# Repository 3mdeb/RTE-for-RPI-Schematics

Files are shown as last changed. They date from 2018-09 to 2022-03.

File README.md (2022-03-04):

# Schematics of the RTE platform for Raspberry Pi

This repository contains source files for Remote Testing Environment schematics.

If you want to read more about this project, here are some useful links:

* Firmware/software:
  - meta-rte - custom firmware for RTE RPi [TBD]
  - [RteCtrl](https://github.com/3mdeb/RteCtrl) - binary for power management on
  board ([MIT license](https://github.com/3mdeb/RteCtrl/blob/master/LICENSE))
* Datasheet (under CC BY-SA 4.0 International License):
  - [RTE RPi v0.1.2 datasheet](https://cloud.3mdeb.com/index.php/s/cM5Mi4w2mjKNpBY)

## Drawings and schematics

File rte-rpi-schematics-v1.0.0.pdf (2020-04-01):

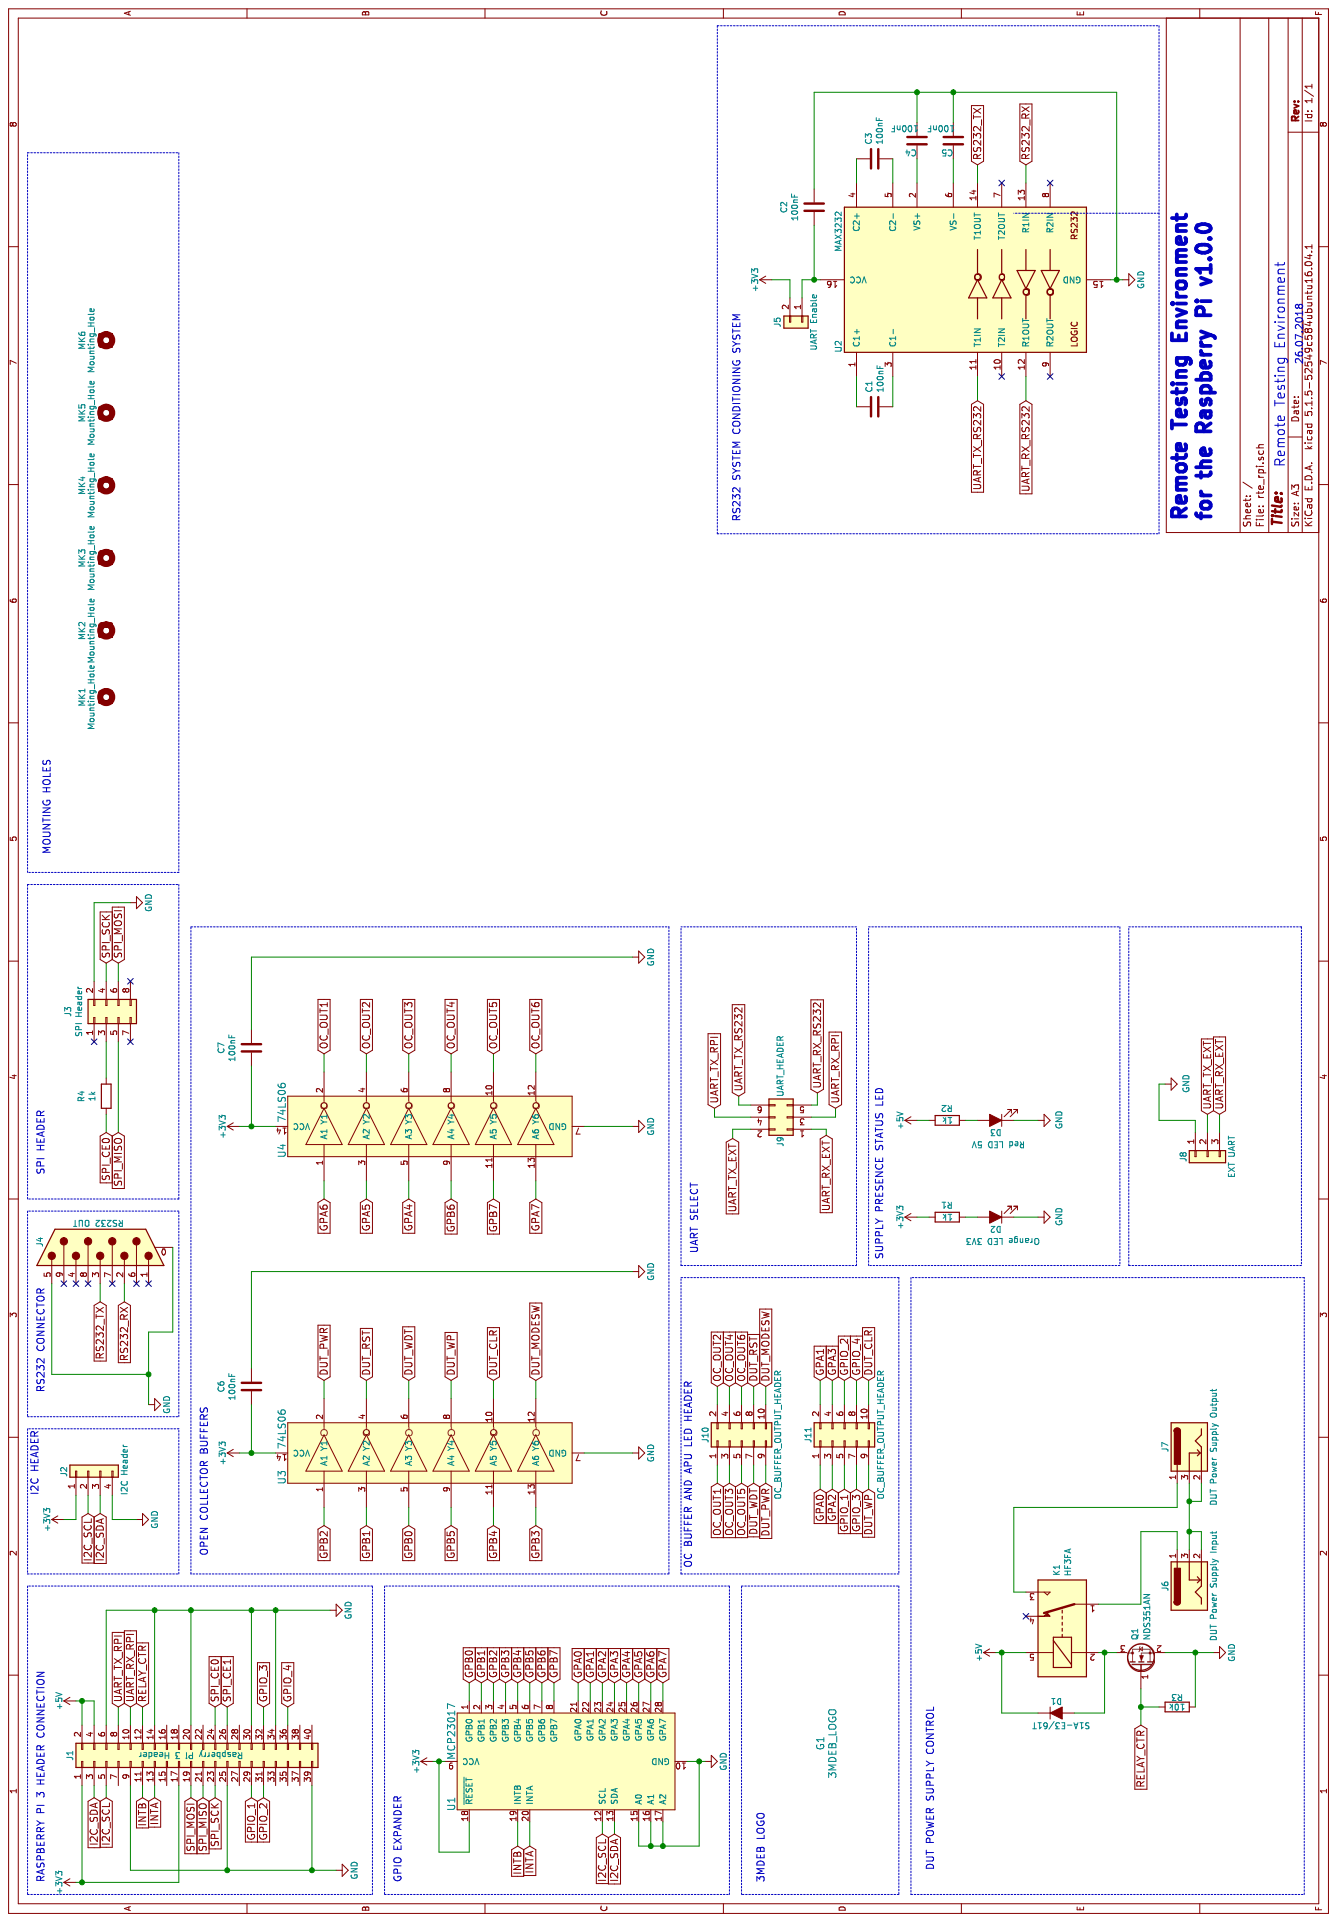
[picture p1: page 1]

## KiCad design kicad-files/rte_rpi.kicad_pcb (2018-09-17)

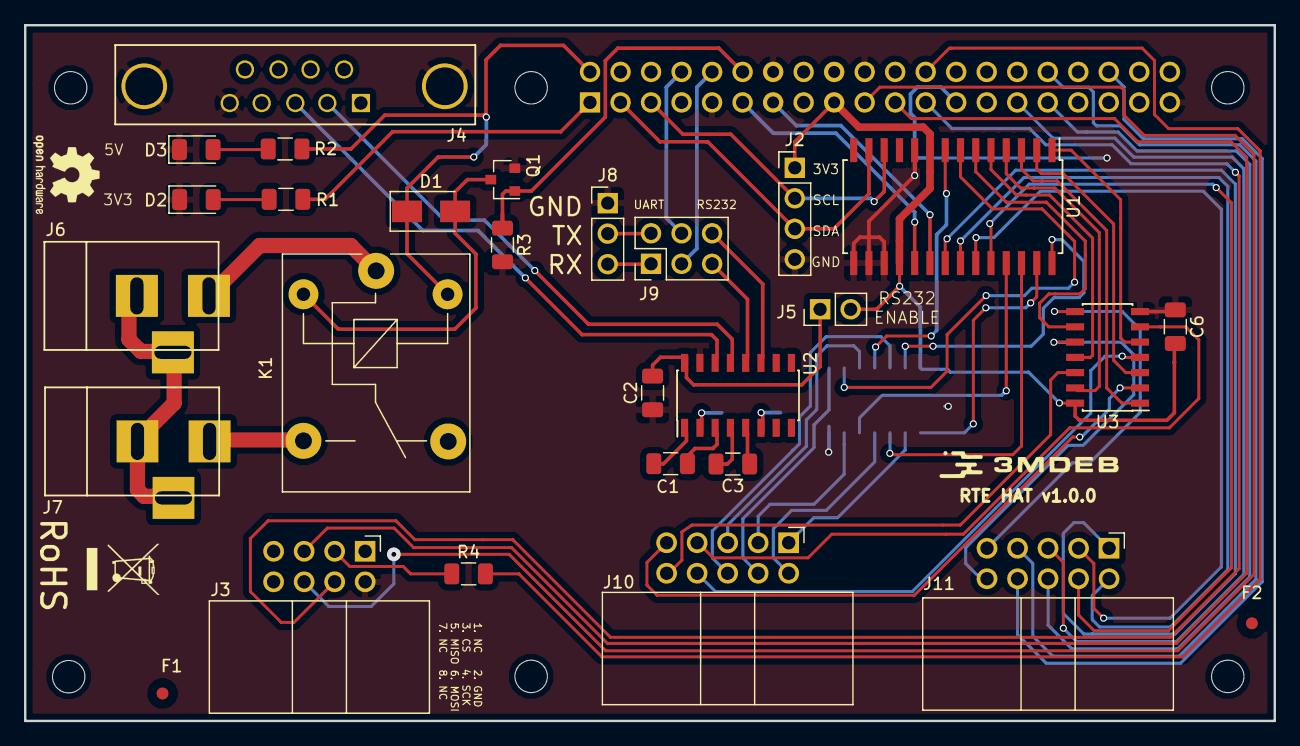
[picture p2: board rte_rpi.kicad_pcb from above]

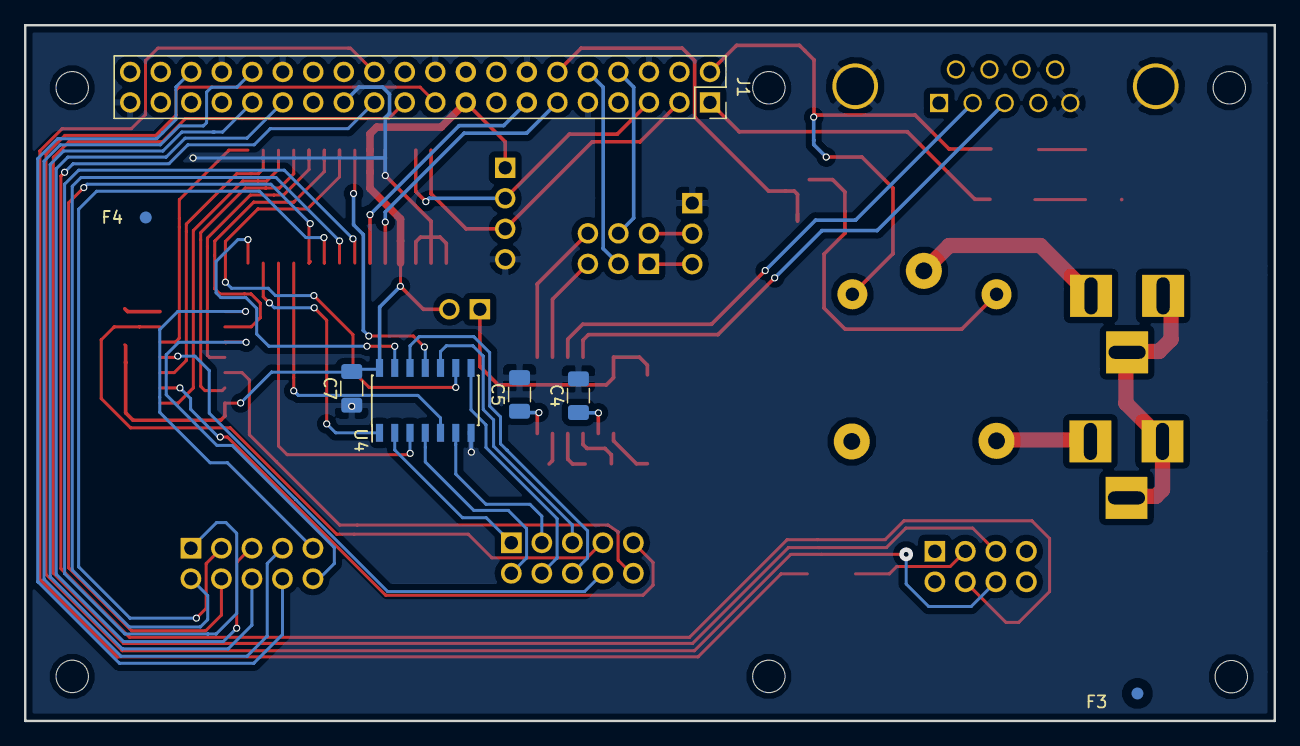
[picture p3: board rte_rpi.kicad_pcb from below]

Board: 2 copper layers, 104.0 x 57.9 mm, 42 parts (5 on the bottom side), 66 nets.

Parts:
C1, C2, C3, C4, C5, C6, C7: 100nF; C_1206_3216Metric
D1: S1A-E3/61T; D_SMA
D2: Orange LED 3V3; LED_1206_3216Metric
D3: Red LED 5V; LED_1206_3216Metric
F1, F2: Fiducial_1mm_Dia_2.54mm_Outer_CopperTop
F3, F4: Fiducial_1mm_Dia_2.54mm_Outer_CopperBottom
G1: 3MDEB_LOGO; 3mdeb_logo
J1: Raspberry Pi 3 Header; PinSocket_2x20_P2.54mm_Vertical
J2: I2C Header; PinHeader_1x04_P2.54mm_Vertical
J3: SPI Header; IDC-Header_2x04_P2.54mm_Horizontal
J4: RS232 OUT; DB9MD
J5: UART Enable; PinHeader_1x02_P2.54mm_Vertical
J6: DUT Power Supply Input; BARREL_JACK
J7: DUT Power Supply Output; BARREL_JACK
J8: EXT UART; PinHeader_1x03_P2.54mm_Vertical
J9: UART_HEADER; PinHeader_2x03_P2.54mm_Vertical
J10, J11: OC_BUFFER_OUTPUT_HEADER; IDC-Header_2x05_P2.54mm_Horizontal
K1: HF3FA; Relay_SPDT_SANYOU_SRD_Series_Form_C
MK1, MK2, MK3, MK4, MK5, MK6: Mounting_Hole; MountingHole_2.7mm
Q1: NDS351AN; SOT-23
R1, R2, R4: 1k; R_1206_3216Metric
R3: 10k; R_1206_3216Metric
U1: MCP23017; SOIC-28W_7.5x17.9mm_P1.27mm
U2: MAX3232; SOIC-16_3.9x9.9mm_P1.27mm
U3, U4: 74LS06; SOIC-14_3.9x8.7mm_P1.27mm

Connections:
+3V3: C6.2, C7.2, J1.1, J1.17, J2.1, J5.2, R1.1, U1.9, U1.18, U3.14, U4.14
+5V: D1.1, J1.2, J1.4, K1.5, R2.1
DUT_CLR: J11.10, U3.10
DUT_MODESW: J10.10, U3.12
DUT_PWR: J10.9, U3.2
DUT_RST: J10.8, U3.4
DUT_WDT: J10.7, U3.6
DUT_WP: J11.9, U3.8
GND: C2.1, C4.2, C5.2, C6.1, C7.1, D2.1, D3.1, J1.6, J1.9, J1.14, J1.20, J1.25, J1.30, J1.34, J1.39, J2.4, J3.2, J4.0, J4.5, J8.1, Q1.2, R3.2, U1.10, U1.15, U1.16, U1.17, U2.15, U3.7, U4.7
GPA0: J11.1, U1.21
GPA1: J11.2, U1.22
GPA2: J11.3, U1.23
GPA3: J11.4, U1.24
GPA4: U1.25, U4.5
GPA5: U1.26, U4.3
GPA6: U1.27, U4.1
GPA7: U1.28, U4.13
GPB0: U1.1, U3.5
GPB1: U1.2, U3.3
GPB2: U1.3, U3.1
GPB3: U1.4, U3.13
GPB4: U1.5, U3.11
GPB5: U1.6, U3.9
GPB6: U1.7, U4.9
GPB7: U1.8, U4.11
GPIO_1: J1.29, J11.5
GPIO_2: J1.31, J11.6
GPIO_3: J1.32, J11.7
GPIO_4: J1.36, J11.8
I2C_SCL: J1.5, J2.2, U1.12
I2C_SDA: J1.3, J2.3, U1.13
INTA: J1.13, U1.20
INTB: J1.11, U1.19
unnamed: C1.1, U2.1
unnamed: C1.2, U2.3
unnamed: C2.2, J5.1, U2.16
unnamed: C3.1, U2.5
unnamed: C3.2, U2.4
unnamed: C4.1, U2.2
unnamed: C5.1, U2.6
unnamed: D1.2, K1.2, Q1.3
unnamed: D2.2, R1.2
unnamed: D3.2, R2.2
unnamed: J3.3, R4.1
unnamed: J6.1, K1.1
unnamed: J6.2, J6.3, J7.2, J7.3
unnamed: J7.1, K1.3
OC_OUT1: J10.1, U4.2
OC_OUT2: J10.2, U4.4
OC_OUT3: J10.3, U4.6
OC_OUT4: J10.4, U4.8
OC_OUT5: J10.5, U4.10
OC_OUT6: J10.6, U4.12
RELAY_CTR: J1.12, Q1.1, R3.1
RS232_RX: J4.2, U2.13
RS232_TX: J4.3, U2.14
SPI_CE0: J1.24, R4.2
SPI_MISO: J1.21, J3.5
SPI_MOSI: J1.19, J3.6
SPI_SCK: J1.23, J3.4
UART_RX_EXT: J8.3, J9.1
UART_RX_RPI: J1.10, J9.3
UART_RX_RS232: J9.E, U2.12
UART_TX_EXT: J8.2, J9.2
UART_TX_RPI: J1.8, J9.4
UART_TX_RS232: J9.6, U2.11

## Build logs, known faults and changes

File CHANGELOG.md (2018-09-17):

RTE for RPi Board changelog
===========================

v0.1.0
------

Added:

* Created the prototype of RTE

v0.1.1
------

Added:

* Fiducials

Modified:

* Resistance value of LED diodes
* Footprint of RS232 connector

v0.1.2
------

Added:

* Resistor for restriction the current of the CS line 

Modifed:

* names of the open-collector buffers outputs

v0.1.3
------

Added:

* Description to the I2C pins
* Description to the UART pins 

v0.1.4
------

Modified:

* Relay symbol in the schematic file
* Route of the relay output
* Placement of the elements: `D1`, `Q1`, `R3`, `J12`
* Placement of the J1 header. From now on, it is on the bottom side

Removed:

* `MK*` signatures from the mounting holes

v1.0.0
------

Added:

* 1x03 pin header for an external UART connection
* `RoHS` logo
* `Crossed wheelie bin` logo
* `Open Hardware` logo

Modified:

* Placement of the MAX3232 IC and related capacitors
* Placement of the SPI pin descripions
* Way of selecting the UART output

Removed:

* `MK*` signatures from the mounting holes

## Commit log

2018-09-17 Added initial version of RTE for RPi
    [rte_rpi-2018-09-11-14-49-09.sch, rte_rpi-2018-09-11-14-54-22.sch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]
2020-03-18 add rte-rpi-schematics-v1.0.0.pdf
